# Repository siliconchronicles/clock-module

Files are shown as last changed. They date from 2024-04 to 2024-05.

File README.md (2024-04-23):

# Compact Clock Module for debugging

Here's my description of a debugging clock generator. This is not a
"clock" in the colloquial sense; it generates pulses to synchronise
sequential digital circuits.

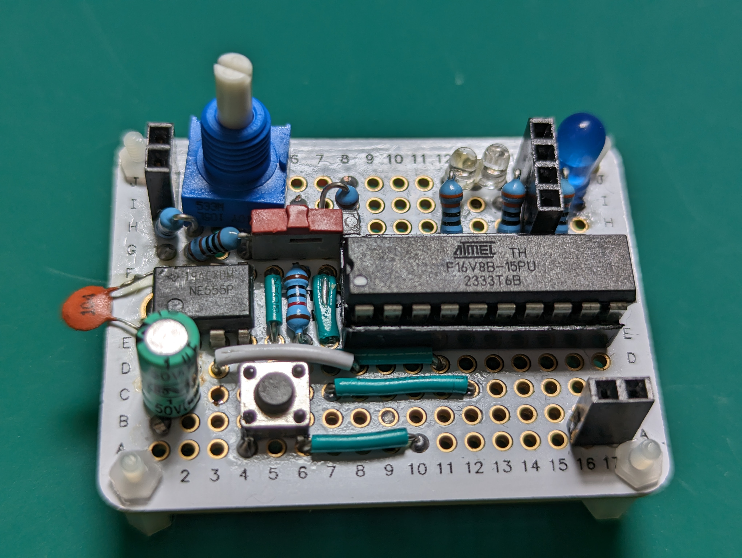
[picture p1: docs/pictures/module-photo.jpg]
Picture of clock module


I call this a "debugging" clock because it's not meant to run regularly and fast. Instead,
it allows me to adjust its speed on the fly (by turning a small knob) and to step-by-step
the circuit it's connected to.

You can see a quick demo of it in action on [my YouTube channel](https://www.youtube.com/watch?v=ZGoPLhaSozs)

<iframe width="560" height="315" src="https://www.youtube.com/embed/ZGoPLhaSozs?si=02fc0bJACHwVjzYZ" title="YouTube video player" frameborder="0" allow="accelerometer; autoplay; clipboard-write; encrypted-media; gyroscope; picture-in-picture; web-share" referrerpolicy="strict-origin-when-cross-origin" allowfullscreen></iframe>

Its main features are:

* Two-mode selector (automatic or single-step) with indicators.
* Adjustable frequency control (0.7Hz to 480Hz). The frequency can be changed while running.
* HLT input: When high, the clock stops running. This input allows electronic control of the clock; if unused,
  you can tie it to ground. Modifying the design to make this line active low is easy if desired.
* Tiny footprint: fits a quarter-size (170 contact) solder-pad breadboard. Requires a few
  wires soldered on the bottom side.
* LED indicator of clock cycles.
* 5V TTL levels.
* Compatible drop-in replacement for [Ben Eater's clock module](https://eater.net/8bit/clock)

If you are familiar with Ben Eater's clock, this one is very similar in functionality
(but more compact and less educational). If you want to understand how this works rather
than just building it, I recommend you watch [his videos](https://eater.net/8bit/clock).

You can build this on a solderless breadboard if you prefer; although my design goal with
this project was to be able to solder it to get a more reliable and stable clock generator
that I can use in multiple projects.

## Building the module

* [List of materials](docs/materials.md)
* [Schematic](docs/schematic.md)
* [Physical layout and build tips](docs/layout.md)
* Programming the PLD (Programmable Logic Device)
  * [Software and hardware](docs/pld-tooling.md)
  * [Logic definitions (CUPL) for the PLD](docs/cupl.md)
* [Testing](docs/testing.md)

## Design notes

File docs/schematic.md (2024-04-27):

# Schematic

To zoom into this, right-click on the image and open in a new tab.

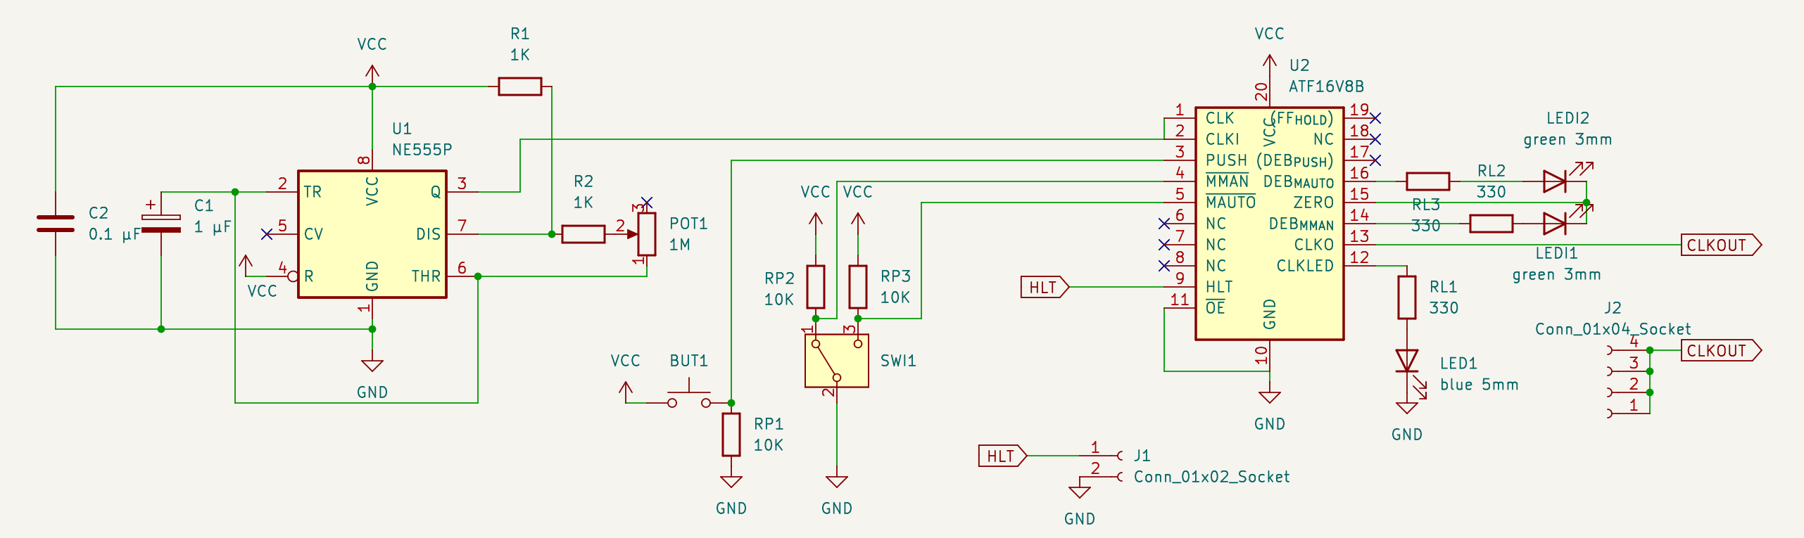
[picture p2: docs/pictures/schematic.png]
Schematic


This is my first KiCAD schematic, so I'm unsure how good it is. I appreciate suggestions
on how to improve it. 

[Source KiCAD schematic available on GitHub](https://github.com/siliconchronicles/clock-module/blob/main/schematic/clock/clock.kicad_sch).

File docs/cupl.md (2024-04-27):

# The "CUPL" code for my clock module

The CUPL source for the ATF16v8 module is in this repo here: [be8clock.pld](https://github.com/siliconchronicles/clock-module/blob/main/cupl/be8clock.pld)

The following text explains the functionality implemented in this file and how it works.

## What the module does

The functionality implemented in this module includes:

* Receives the input clock from the 555 timer
* Accepts (and debounces) input from the mode toggle switch
* Accepts (and debounces) input for the single-step push button
* Receives a HALT signal
* Providing the output clock in two pins. One is used for the blue LED, and the other is for
  the clock connector.
    * Output is low if halted.
    * Output copies the input clock in automatic mode
    * In manual mode, output is set while pushing the button, and cleared once a full
      cycle (2 rising edges) of the input clock passes with the released button.
      Note that the length of this pulse is still controlled by the potentiometer.
* Generates output signals for the mode indicator LEDs

## Implementation details

### Schematic

The following schematic reflects the logic built by the CUPL program, and can be used as reference.

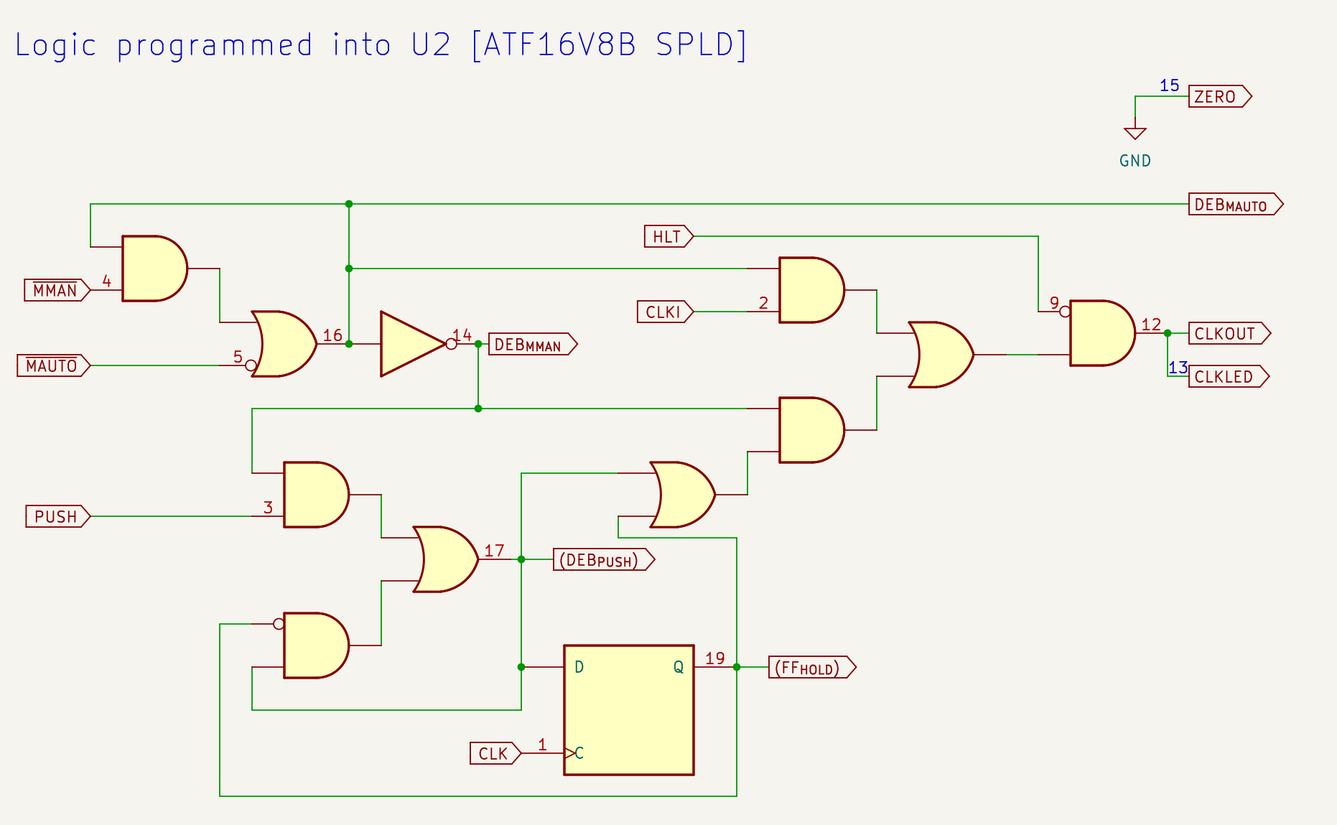
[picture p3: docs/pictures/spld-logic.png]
SPLD logic schematic


Numbers correspond to pin numbers in the U2. You can open the image in a new tab to zoom in.

### Input signals

The input pins are defined as follows:

```
PIN 1 = clk ;    /* 555 based clock */
PIN 2 = clki ;    /* tied to pin 1; clk can not be used in formula */
PIN 3 = push ;    /* push-button: trigger clock pulse */ 
PIN 4 = !mman ;   /* toggle set to manual */ 
PIN 5 = !mauto  ; /* toggle set to auto */ 
PIN 9 = hlt ;     /* halt clock */ 
```

Pin 1 is the standard clock input for the ATF16V8 flip-flops. However, the value on pin 1
can not be used as an input for logic gates if it is used as a clock, so the input clock is
connected to pin 2 (both pins are bridged together).

Pin 3 is attached to the push buttons (which defaults to a low value with a 10K pull-down,
and pressing it drives it to Vcc).

Pins 4 and 5 are attached to the two end terminals of the mode switch. The common point of
the switch is attached to the ground, and both switches have a 10K pull-up. This means that
one side will go high and the other low when switching. The names of the input signals
are `mman` ("mode=manual", for single-step) or `mauto` ("mode=automatic" for running
oscillator).

The exclamation mark in the pin definitions indicates that the signals are active-low. Note that
in logic formulas used later, using a name as `mauto` will be interpreted as "the signal `mauto`
is active" (i.e. low), not to be confused with "the signal `mauto` is high". CUPL focuses
on providing formulas based on logic and leaving the active-high/active-low decision as
implementation details in the pin definitions.

Pin 9 is the HLT (halt) signal.

The ATF16V8B has three-state functionality that I'm not using. The "output-enable" pin is
always pin 11 and needs to be defined in the CUPL file:

```
PIN 11 = !oe ;
```

### Switch debouncing

The mode switch can have (as any mechanical switch) some bouncing, so the circuit can not
rely directly on pins 4 and 5 to identify the mode. There could be states while the switch
is moving that none of them are active. I used the PLD cells to implement a SR-latch 
(set/reset latch) that is set/reset based on the mode. This ensures that a single mode
is selected at any time. When the switch gets a known
position, that event is used as a set or reset signal. While the switch travels or bounces,
the latch will keep its current state.

Note that the state of a set/reset latch can be defined as the following logic formula:
 `Q' = S # (!R & Q)`.

Notes:
* The formula above uses the CUPL syntax where `#` means "or", `&` means "and", and `!`
  means "not".
* `Q'` is the "next state", and `Q` is the current state. `S` is the "set" signal, and `R` is "reset".
* You can then read the formula above: "the SR-latch will be high either only if it's being set,
  or if it was already high and not being reset.

With that, we can build the following pieces of the CUPL file defining the latches as
formulas.

```
PIN 14 = deb_mman ; /* debounced mman */
PIN 15 = zero     ; /* shared ground for indicator LEDs */
PIN 16 = deb_mauto ;  /* debounced mauto */

/* SR-latch logic (set priority). Q' = S # (!R & Q) */
deb_mauto = mauto # (!mman & deb_mauto);  
deb_mman = !deb_mauto;

zero = 'b'0;
```

The name `deb_mauto` means "debounced mode=automatic". An active `mauto` signal will be
the "set" operation in the latch. An active `mman` signal will be the "reset" operation.

The name `deb_mman` means "debounced mode=manual". I don't need another latch for this
signal. It's always the opposite of `deb_mauto`. Doing this guarantees that consistently exactly one of
the `deb_xxx` signals will be active at any given time.

These two signals are sent to pins 14 and 16 which are used for the mode indicator LEDs
(the two small green LEDs). Pin 15 is set to a value which is always low. This is a
small hack to have a "ground" value for the LEDs, which reduces a bit the wiring/soldering
needed.

### Single step button

The single step push button uses debouncing, and also relies on a SR-latch called `deb_push`.
The mechanics of this latch are a bit different than before.

Pushing the button while on single step mode acts as a
"set" signal. However releasing is not a reset (otherwise the bounces will just toggle
the latch quickly). Instead, the next clock rising edge after the button is pushed will set
active one of the PLD flip-flops called `ff_hold`. The output of `ff_hold` will act as
the reset signal, which will clear `deb_push`. When `deb_push` is low, `ff_hold` will go
low the next rising edge.

The formula definition we used for SR-latches gives priority to "set" signals. If both
the "set" and "reset" are high, the latch will be set and ignore the reset. That means
that if `ff_hold` is already set, but the button is still pushed, the latch will stay
active (and thus, `ff_hold` will too).

Our clock output will be the result of `deb_push # ff_hold`. So the clock will be active
as soon as the button is pressed, and will keep active while it's pressed (because of
`deb_push`). Once it's released, the next rising edge will bring `ff_hold` up (if it
wasn't already due to a long push). That will reset `deb_push` but keep `ff_hold` up for
a full clock cycle.

If you press the button very very briefly, the clock output will stay for an amount
shorter than a cycle (until the next rising edge), and then a full extra cycle, so a
total which is at least one cycle and less than two cycles.

To define this, we need both signals. Because of the design of the ATF16V8, we need to
assign a signal to an output pin if we want to use one of the flip-flops, and also if
we want to feed an output signal back into the chip (which is required in a SR-latch).
Rather than defining a `PIN`, you can define those as `PINNODE` (which means "use this
PIN, but this is not a real output"). In practice it's the same (and the signal in fact
comes out of the pin), but it documents the intent:

```
PINNODE 17 = deb_push ;  /* debounced push */
PINNODE 19 = ff_hold ; /* hold while waiting for clock after push */

/* SR-latch logic. set priority */
deb_push = (push & deb_mman) # (!ff_hold & deb_push); 
ff_hold.d = deb_push;
```
The `ff_hold.d` syntax states that `ff_hold` is a D flip-flop (which makes it
automatically clocked with the CLK pin of the PLD).

### Signal output

The main outputs are:

```
PIN 12 = clko ;   /* clk output */ 
PIN 13 = clkled ; /* clk led indicator */ 

...

clkled = clko ;
clko = !hlt & ((clki & deb_mauto) # (deb_mman & (deb_push # ff_hold)));

```

Both pins produce the same signal and are interchangeable. They are repeated for
convenience putting the board together.

The output signal formula contains the following parts:

* `!hlt & (...)` makes the output low if hlt goes active.
* `(clki & deb_mauto)` passes through the clock input (pin 2) when the debounced mode latch is set to auto
* `(deb_mman & (deb_push # ff_hold))` is used in single step mode and computes the
  clock formula `deb_push # ff_hold` described before.

## Possible adjustments

If you desire slightly different functionalities, these are some simple changes that you
can make:

* You can remove the hlt signal and references to it if you don't need a halt
* You can define the PIN 9 as !hlt to make the halt signal active-low instead of active
  high.
* You can define PIN 18 as a negation of the clock output line, which allows you to
  have a negative phase clock.
* If you prefer to reverse which side of the switch corresponds to which mode, you may
  want to switch numbers of pins 4 and 5

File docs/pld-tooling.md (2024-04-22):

# What do you need to use the PLD (ATF16V8)

## What is a PLD?

The key to this module's compactness is a "Programmable Logic Device" (PLD). Some people
call them "PAL" or "GAL" instead. These chips don't do anything out of the box; they contain a
collection of "cells", each cell containing a flip-flop and a few gates. Using a
compatible programmer (many EEPROM programmers will do the trick), you can interconnect
those existing components to create different behaviours, and map them into different
input/output pins. 

## What do you need to use them?

* Hardware: To "configure" a PLD, you need an EEPROM programmer that supports this chip. 
  **Not every EEPROM programmer does; in particular, Arduino-based programmers can't write PLDs**.
  I'm using a T48, the successor of the popular TL866-ii+; both are relatively cheap and
  can write these PLDs. The instructions below assume you have one of those.
* Software: You need two main pieces of software. The first one transforms some
  definitions describing what you want the chip to do into a cell interconnection
  that can be "burned" into the chip. The output of that is a ".jed" file. Then, you can
  use software specific for your programmer to burn the .jed file into the device.
  * I use Atmel's "WinCUPL" software, which generates the JED file. Other alternatives include
    PALASM (very old!), GALasm (non-commercial use only), and Galette (which has been
    intermittently unmaintained but seems to be active as of April 2024).
    These use very different syntaxes to specify the logic definition.
  * For the T48 or TL866, the manufacturer-provided software can do this, although I use 
    [minipro](https://gitlab.com/DavidGriffith/minipro) (Note: I added the T48 support in minipro, and it is still experimental, but it seems to work for me).
  * **Shortcut**: If you have the JED file and don't plant to change it, you can skip the compilation and go straight to programming.
    The [JED file for my module is here](https://github.com/siliconchronicles/clock-module/blob/main/cupl/be8clock.jed) (follow the link and click the download button).

## WinCUPL

Atmel, owned by Microchip makes the ATF16V8. The chips are supported and still
manufactured. Microchip has a philosophy of rarely stopping to make old parts, so designs
relying on their ICs can keep being maintained. However, there's not a lot of effort in
improving the software support features. The official software for using older PLDs is
called [WinCUPL](https://www.microchip.com/en-us/development-tool/wincupl) and can be
downloaded for free from [Microchip's website](https://www.microchip.com/en-us/products/fpgas-and-plds/spld-cplds/pld-design-resources); it
asks for a license number, but there's a free one on the download page itself.

WinCUPL is very old, has a UI that looks taken out of the '90s (because it probably is),
and includes an IDE that's extremely unreliable: For me, the syntax highlighter messed up
the colours of my code after a bit of edition, and it crashed after every compile to JED
(the compile worked but then the IDE closed itself). So I avoid it like the plague.

However, when you install it, you get some command line tools that are actually quite
reliable. It also comes with several example files to help you understand how to design the logic
formulas that get translated to cell interconnects. I've run it in Windows 10 and
Linux (through the WINE emulation layer), and it works ok. You'll need to be familiar
with a command line.

Installing it is relatively straightforward. By default, it goes into `c:\Wincupl`. If you
have a cupl file like [the one for this project](https://github.com/siliconchronicles/clock-module/blob/main/cupl/be8clock.pld),
you can build it with this command:

```
c:\wincupl\shared\cupl.exe -j -u c:\wincupl\shared\Atmel.dl be8clock.pld
```

Or in Linux:
```
wine 'c:\wincupl\shared\cupl.exe' -j -u 'c:\wincupl\shared\Atmel.dl' be8clock.pld
```

If your file is correct, you will get a `be8clock.jed` file.

## minipro

minipro is an open-source programmer that's compatible with the TL866 family of devices
by xgecu (including the T48 and T56). These reasonably priced, widely available
devices support a wide range of ICs.

If you have it, you can install minipro (check their webpage for up-to-date install
instructions), insert the ATF16V8 in the device, and write the JED file with the following
command:

```
minipro -u -w be8clock.jed -p ATF16V8B
```

After minipro writes the cell configuration into the chip, it will verify. If
verification fails, check if you're using the right IC (see below) and that there are no
compilation issues with your cupl file. **Don't use the misconfigured PLD**. A badly
written PLD could have an internal invalid configuration that shorts itself or overheats, and
you may end up damaging the PLD or other components.

## Using a different PLD

There are a few variants of the 16x8 PLD that are slightly different. Most will support
this project but may have different programming algorithms. Check the following if you
are using a different device:

* The cupl file has a "device" line that I've set to `g16v8a`. If your device is
  different you may need something else here. The WinCUPL buggy IDE has a list of
  devices and specifies for the chip name what's the corresponding "device" label
  that you required in the CUPL file.
* Different variants may need different programming algorithms or voltages.
  minipro may require you to change the `-p ATF16V8B` to something else. Check the
  output of `minipro -l` to see if your device is listed.

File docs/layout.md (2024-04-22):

# Layout

This section describes the physical layout of the circuit. It relies on the breadboard
markers with rows A to J (bottom to top), and columns 1 to 17 (left to right).

## Cutting tracks

Some of the tracks need to be interrupted with a track cutter. Test that the track is properly cut with a multimeter. It's easy to make the cuts before you start soldering. But cuts are
easily bridged with solder, so re-test after you're done soldering and clean/re-cut any
bridges.

You need to cut through the following tracks:

* Row 4, between F and G
* Row 5, between G and H
* Row 12, between H and I
* Row 14, between H and I
* Row 16, between H and I

## Component positioning

The grid below shows you which component goes in each breadboard hole. "*" markers indicate there's something
unusual there, read the notes before soldering. Numbers ①,②,③,... indicate the ends of jumper wires.

|Row| 1| 2| 3| 4| 5| 6| 7| 8| 9|10|11| 12| 13| 14|15| 16| 17|
|---|---|----|-----|-----|---|-----|-----|-----|----|--|--|---|---|---|--|---|---|
| J |J3(VCC)⑪ | |POT  | |POT | | | ⑪  | |  |  | LEDI1+ | LEDI-*| LEDI2+ |J1| LED1+ | LED1- |
| I |J3(VCC)  | | | | | ⑫ | | | |  |  | RL1 | | RL2 |J1| RL3 | ⑫ |
| H |R1 |R1  | |POT:C| | | RP2 | RP2 | |  |  | | | |J1| | |
| G |RP3* |R2  | | R2  |RP3*/SWI|SWI:C| SWI | RP  | |  |  | RL1 | | RL2 |J1| RL3 | |
| F |U1:+⑩ |U1  |U1①*| U1  | ③ | RP1 | ④  | U2+ |U2  |U2|U2| U2 | U2 | U2 |U2| U2 | U2⑨ |
| | | | | | | | | | |  |  | | | |  | | |
| E |U1:- |U1①*|U1 | U1⑩| ③ | RP1 | ④  | U2② |U2②|U2|U2| U2 | U2 | U2 |U2| U2 | U2-⑨  |
| D | | | ⑧ | BUT |  ⑥ | BUT | | ⑧ | |  |⑥| | | |  | | |
| C |C1- |C1+ | | | | | ⑦ | | |  |  | ⑦ | | |  | | |
| B |⑬ | | | C2  | | | | | |  |  | | | |  | | ⑬ |
| A |C2* | | | BUT | |BUT⑤ | | | |⑤|  | | | |  |J2(HLT)|J2(GND)|

Notes:
* RP3 goes on the bottom side of the board. The pin on G5 shares the space with one of the side pins of SWI, so you'll have to get them together before soldering. Solder the other pins of SWI first so the switch stays in place before fitting in the wire from RP3 and soldering that.
* Jumper wires ①, ②, ⑨, ⑩, ⑪, ⑫ and ⑬ go on the bottom side of board. Except for ⑫ and ⑬ they share pins with other components. You will need to solder the wire and pin together.
* LEDI- is the place where both cathodes for LEDI1 and LEDI2 go together. Usually you should be able
  to fit both without issue. Make sure you do so before soldering.
* The "-" and "+" sign tell you the orientation of polarized components. For capacitors use
  the obvious meaning. For LEDs, "+" is the anode. For ICs, "+" is the Vcc pin, and "-"
  is the GND pin.
* The ":C" refer to the "common" pin in SWI and POT
* In the clock I built and photographed, you can see C2 in a different location, directly soldered to the power pins of the 555; that's because it was a "late" addition so I had to hack it in after everything else was soldered. The location above should be a bit more convenient, although the decoupling effect may be a bit weaker and I haven't tried it (decoupling is important here, otherwise you get clock pulses on ground, which are read by some circuits as double pulses). So let me know if you seem to have issues with this.

## Build recommendations

The following sequence for putting everything together should be reasonably convenient:

1. Start with the components that go across the middle: RP1, wires ③ and ④ . After clipping the ends of RP1, keep the bits of wire, you'll need them
2. Place the socket for U2 (or a pre-programmed U2 directly if you prefer not to use a socket) in place. Make sure it is the right way in (unlike mine :) ) and put one of the bits of wire to form ② between pins 1 and 2 (at locations E8 and E9, under the board). It doesn't need to go in the hole, just help you build the bridge. Solder pins 1 and 2; with the wire there the solder will form the desired bridge between the two pins.
3. Make sure the socket is tightly in place (it will be harder to move around once you solder the rest of the pins). Put wire ⑨ in position (locations E17 and F17), you can use the other bit of wire from step 1. Solder those in.
4. Solder the rest of the U2 socket.
5. Solder pins 1 and 5 of U1 (locations E1 and F4) so it stays in place
6. Solder jumper wire ① below the board. ① and ⑩ cross each other so at least one of them needs insulation. These share pins with U1.
7. Solder jumper wire ⑩, ensuring a good connection between wire, IC, and PCB. You can test from the other side with a multimeter that pins 4 and 8 of the timer IC have a continuous path.
8. Solder remaining pins of U1
9. Place in BUT and ⑤. Ensure the button is in the right orientation (there should be no connection between A4 and A6 if the button is not pushed). Solder the common joint (location A6). Solder the rest of the pins for the push button and the wire.
10. Solder ⑥ and ⑧. Then solder ⑦.
11. Solder J2; then ⑬ (below the board). Then C2
12. Solder C1, checking the polarity.
13. Solder J3 and ⑪ on the backside. The shared pin here is a tricky one, there's not a lot of space for the wire to go in.
14. Solder R1 and R2. They will be at a bit of an angle, there's no space to get them flush.
15. Solder the point shared by SWI and RP3 (location G5). Remember that RP3 goes below the board (it has enough space to go flush). Solder the other point of RP3
16. Solder the common point of POT. Depending on the physical dimensions of POT and SWI you may need to squeeze/bend them slightly to fit both next to each other (which should be doable while only one pin of each is soldered)
17. Solder the rest of POT and SWI
18. Solder RP2
19. Solder ⑫. That's the last jumper wire!
20. Solder J1
21. Solder all of RL1, RL2, RL3
22. Solder all of the LEDs. note that the 3mm LEDs share the cathode pin at J13, put both through before soldering.

This should be all! Once you're done you can program your 16V8 and place it into the socket.

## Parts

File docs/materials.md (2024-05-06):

# Materials for the clock module

The build is designed to be made on a 1/4 size solderable breadboard (17 holes wide,
10 tall) with tracks. Like this:

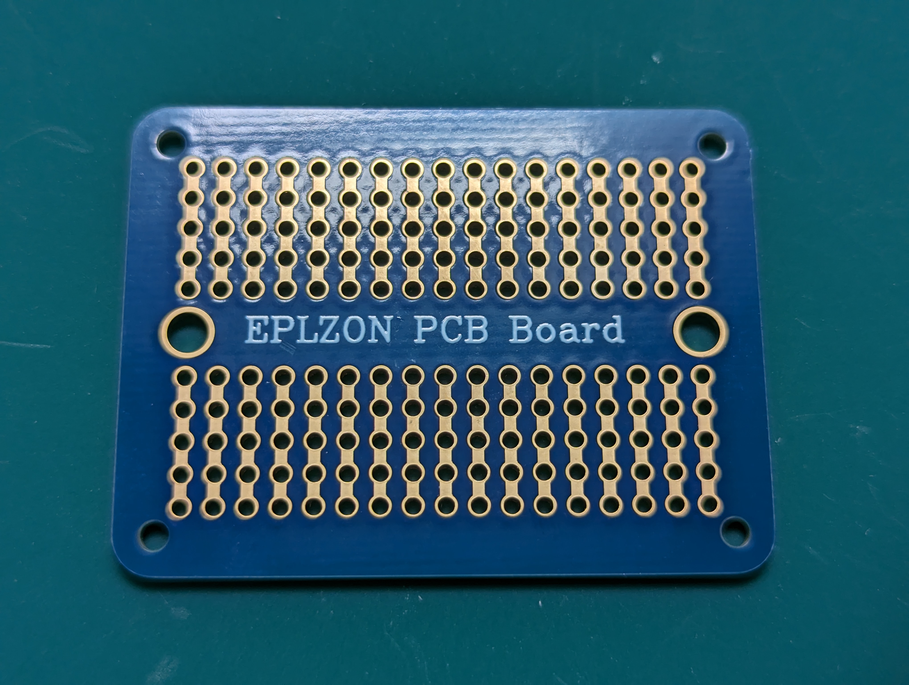
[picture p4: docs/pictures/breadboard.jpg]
Base Breadboard


# Components

* C1: 1 µF (timing capacitor)
* C2: 0.1 µF (decoupling capacitor)
* R1: 1 KΩ (discharge resistor)
* R2: 1 KΩ (charge resistor)
* 3 x RP: 10 KΩ (pull-up/pull-down resistors)
* 3 x RL: 330 Ω (LED protection. You can change this if you like your LEDs brighter/dimmer)
* LED: blue 5mm LED (clock output indicator. You can use a 3mm if you prefer)
* 2 x LEDI: green 3mm LED (mode indicator)
* POT: 1 MΩ linear potentiometer (speed control. Make sure it's not too bulky; space is tight)
* BUT: push button, normally open (single-step button)
* SWI: SPDT switch, 3 inline pins. (mode selector. Make sure it's a narrow one to fit the allocated place)
* J1 (CLK): 4-way, single-row PCB socket (connector for clock output. It's convenient to have a multiway connector to attach to multiple circuits, but you can do with less ways if you prefer).
* J2 (HLT/GND): 2-way, single-row PCB socket (connector for GND and HLT lines)
* J3 (VCC): 2-way, single-row PCB socket (connector for VCC. if you get a 1-way it may be easier to place, but I couldn't find those).
* U1: 555 (timer IC)
* U2: ATF16V8B (Simple programmable logic device)
* a DIP-20 socket for U2 (not required, but strongly recommended)
* some jumper wires
  
Here's a picture of everything labelled:

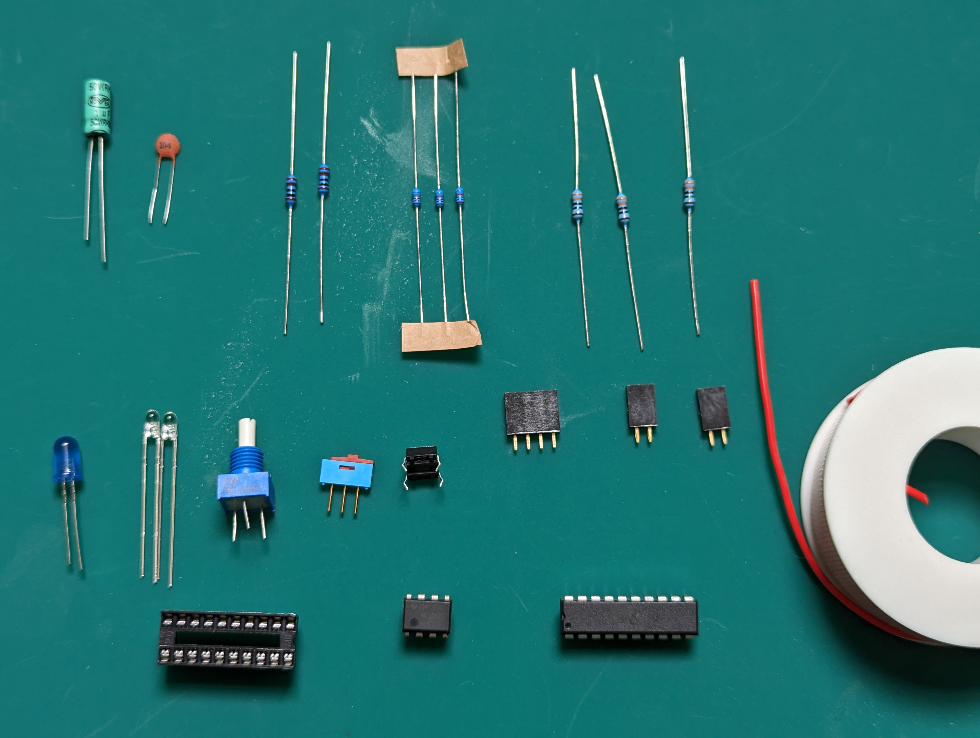
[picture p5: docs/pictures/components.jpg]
Components


I've added some nylon "legs" which are M2 nylon spacers + nylon nuts; but the size of
those may depend on the specific solderable board you use. Those are entirely
optional.

## Data sheets

* [NE555P](https://www.ti.com/lit/ds/symlink/ne555.pdf) Precision Timer
* [ATF16V8](https://ww1.microchip.com/downloads/en/devicedoc/atmel-0364-pld-atf16v8b-8bq-8bql-datasheet.pdf) High-performance EE PLD

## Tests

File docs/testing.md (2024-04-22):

# How to test this clock module

## Basic functionality test

Connect a jumper wire from GND to 0V in your power supply (or the 0V rail of a powered
breadboard). Connect the HLT line to 0V too. Connect the VCC line to 5V.

As soon as you power up, one of the green LED indicators should light up. If it's the
one on the right, toggle the switch.

You should see a blinking blue LED. If it doesn't blink turn the POT knob around. This
should change the blinking speed, going from fast at one end, to slow at the other.
At the fast extreme you probably can't see the blinking, just the light looking a bit
more dim.

Leave the speed at something reasonably high (pulses should be short, or "invisible"),
and toggle the switch to single-step mode. After this, the push-button should turn the
blue LED once. The LED should stay on while you keep the button pressed. Once released
it will go off, possibly after a short delay (the delay will be longer if you move the
knob to a "slow" speed).

Finally, put the clock back in automatic mode, and try moving the HLT line to 5V and back
to 0V. The clock should stop immediately when the HLT line is not on GND.

That's it!

## Troubleshooting

### General advice

If it doesn't work, something may be misplaced, or the PLD may contain the wrong logic.
A simple way to test is removing the PLD completely from the socket, and putting a jumper
wire in the socket from pin 1 to pin 12. You should have the blinking blue LED
functionality, and the potentiometer should still adjust the speed (the switch and single
step will not work without the PLD). If this doesn't work, the problem is the 555 side
of the circuit and you can debug that. If that works, check that the programming of
your ATF16V8 worked ok, and the connections around switches and PLD

### Double counting

A problem I experienced with a counter is that the LED output looked visually ok, but
when connected to a counter, each pulse counted as two rather than one. After some
debugging, I found out that some clock pulses were detectable on ground due to power
surges in the 555, and that created a very short "double pulse" at the beginning of
each clock cycle.

In my case, that was because I forgot to add C2 to the original design. If it fails for
you, check that C2 is properly soldered. If you still have this issue, it may be worth
soldering it directly to the 555 pins like in [this picture](https://github.com/siliconchronicles/clock-module/blob/main/docs/pictures/module-photo.jpg).

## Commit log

2024-04-20 Fix pin numbers to match usage
2024-04-21 Add schematic
    [clock.kicad_sch]
2024-04-21 Add link to schematic source
2024-04-27 Add schematic to documentation
2024-04-27 Update schematics with better notation
2024-04-27 Update schematic
    [clock.kicad_sch]
2024-05-06 Add schematic title/date
    [clock.kicad_sch]
